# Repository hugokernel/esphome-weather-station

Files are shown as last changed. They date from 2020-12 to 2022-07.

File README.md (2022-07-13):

# ESPHome Weather Station

Read this in other language: [French](README.fr.md)

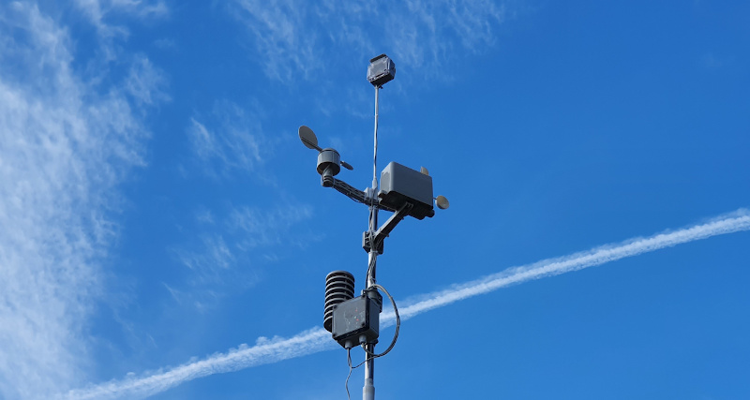
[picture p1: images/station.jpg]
Main photo of the weather station


## Introduction

The electronic part of this weather station is based on the model described in an article in Elektor magazine published in May 2020 entitled [Remake Elektor weather station](https://www.elektormagazine.com/labs/remake-elektor-weather-station) (an evolution of ESP32 Weather Station described in an article in the same magazine in January 2019).

The article details the creation of a weather station based on a set of sensors referenced WH-SP-WS02 ([Datasheet](docs/Weather_Sensor_Assembly_Updated.pdf)) whose original electronics are removed to be replaced by a sensor daughter board relaying the information to a motherboard built around an ESP32 (ESP32 Pico Kit).

An OpenSource firmware [GitHub - ElektorLabs/191148-RemakeWeatherStation: RemakeWeatherStation](https://github.com/ElektorLabs/191148-RemakeWeatherStation) is available to run the whole system. Unfortunately, I did not find my happiness with it, it is not yet complete enough and suffers from some shortcomings that make it very difficult to use it as is.

I therefore decided to use ESPHome as a replacement for the original program in order to simplify the development of functionality but above all to greatly extend its capabilities.

The board detailed in Elektor's article is finally limited to a voltage converter and a 5V/3V voltage adaptation for the ESP32.

It is therefore quite simple to recreate this weather station independently of Elektor's PCB. For the connections, please use the data included in the YAML file.

With the kind [permission of Elektor](https://www.elektormagazine.com/labs/remake-elektor-weather-station#comment-70057), the schematic diagrams are available here:  [Schematics](schematics/).

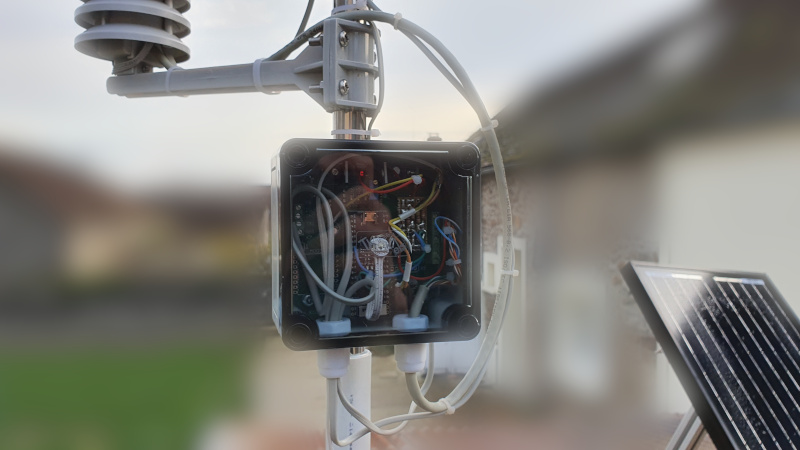
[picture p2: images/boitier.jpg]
Case photo


### Inspirations

* [Remake Elektor weather station | Elektor Magazine](https://www.elektormagazine.com/labs/remake-elektor-weather-station)
* [GitHub - mkuoppa/esphomeweatherstation: ESPHome based weatherstation station](https://github.com/mkuoppa/esphomeweatherstation)
* [ESP8266 Weather Station - with Wind and Rain Sensors | Tysonpower.de](https://tysonpower.de/blog/esp8266-weather-station)

## Features

* Measurement of temperature / relative humidity / atmospheric pressure
* Wind speed / Direction
* Precipitation daily / per minute
* Ambient brightness
* Input voltage
* Solar panel:
  * Voltage
  * Current
  * Power
  * Daily accumulated power
* RGB status led with WS2812
* All ESPHome features
  * MQTT
  * OTA (Over The Air updates)
  * [The list is long](https://esphome.io/)

Note: On the main picture of the weather station, there is a box on top, it is an [independent rain detection module](https://github.com/hugokernel/esphome-rain-detector).

## Installation

In order to install the firmware on the ESP32, I invite you to follow the procedure described on the ESPHome website: [Getting Started with ESPHome](https://esphome.io/guides/getting_started_command_line.html)

## Electronics

The Elektor electronic board is to be used as is or, in view of its simplicity, to be reproduced on a test board.

The Elektor publication is wrong, in fact, they use GPIO 34 (wind speed) and 38 (precipitation measurement) directly without a pullup resistor,
Moreover, these inputs / outputs do not integrate a pull-up resistor, **so it is necessary to add a pullup resistor (~10kOhms) on GPIO34 and GPIO38**.

## Mechanical

For the mast, I used a metal reinforced PVC tube that you can find in any DIY store in the plumbing department. In order to fix it on a wall, I modeled it on OpenSCAD [one piece](wall_pipe_support.scad) that I then printed in PETG.

Here is the printed piece next to the box containing the solar panel charger controller:

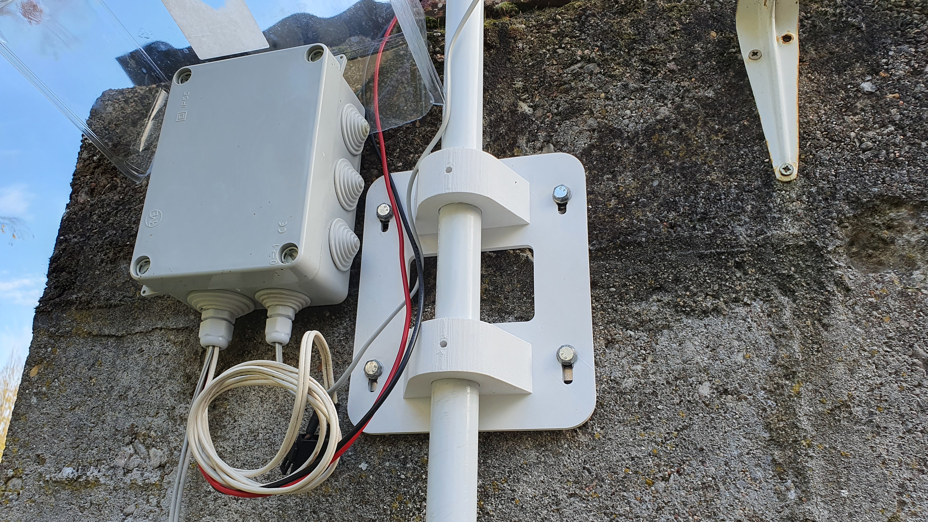
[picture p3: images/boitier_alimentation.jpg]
Photo of the power supply box


## Powering

One of the flaws that I reproach to the original Elektor board is to have linked the technology of the power source to the motherboard (in this case the lead battery), indeed, a [MAX8212](docs/MAX8211-MAX8212.pdf) used with some peripheral components allows to cut the power supply when it goes below a threshold defined by the value of 3 resistors. This threshold has been chosen to protect a lead battery.

Since a weather station is supposed to stay on all the time, I don't really understand the above choice because:

* We use a solar panel to charge the battery but in this case we are obliged to use a charge regulator which also protects the battery and therefore the integrated protection circuit is redundant and can even cause problems.
* The station is connected to an unlimited power source (domestic power via a regulator) and in this case the protection circuit is useless.

In the 2 cases mentioned above, a strong link is inserted on the motherboard with the battery technology, which should be done, imho, on an independent card / module.

For my part, I chose to power my weather station via a [30W solar panel](https://www.amazon.fr/gp/product/B07MZKLS4Z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) and a [relatively basic charge controller](https://www.amazon.fr/gp/product/B07K57WZVP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).

If you are using Elektor's motherboard with an independent load controller module, do not forget to lower the cut-off threshold of the MAX8212.

At the output of the solar panel, the [INA219](docs/ina219.pdf) circuit allows the power generated by the solar panel to be measured. I plan to replace it with [INA3221](docs/ina3221.pdf) in order to also measure the total consumption of the weather station and help me to refine the global consumption (a RFLink with [OpenMQTTGateway](https://github.com/1technophile/OpenMQTTGateway) and a second ESP32 kit is connected to the station).

I use a 7A lead battery recovered from an old inverter.

To size the whole thing, I recommend the [BatteryStuff Tools](https://www.batterystuff.com/kb/tools/solar-calculator.html) tool which is very handy.

Currently, I can't say that I have succeeded in making my weather station totally energy independent because of a bad exposure of my solar panel and a too high consumption of an additional module (rain detection module).

## Explanations

### Measurement of temperature / humidity / atmospheric pressure

These 3 quantities are measured by a Bosch BME280 sensor and its configuration in ESPHome is as follows:

```yaml
  - platform: bme280
    address: 0x76
    update_interval: 60s
    iir_filter: 16x
    temperature:
      name: "${friendly_name} temperature"
      oversampling: 16x
    humidity:
      name: "${friendly_name} humidity"
      oversampling: 16x
    pressure:
      name: "${friendly_name} pressure"
      oversampling: 16x
```

The sensor is to be put inside the box containing the original sensor electronics.

Initially, I also included an AM2320 sensor to compare the sensor values with the following configuration:

```yaml
  - platform: am2320
    setup_priority: -100
    temperature:
      id: am2320_temperature
      name: "${friendly_name} AM2320 temperature"
    humidity:
      id: am2320_humidity
      name: "${friendly_name} AM2320 humidity"
    update_interval: 60s
```

The temperatures and humidities of the sensors were averaged before being sent to Home Assistant (see below), it was of course possible to access the data of each sensor.

```yaml
  - platform: template
    name: "${friendly_name} temperature"
    icon: "mdi:thermometer"
    unit_of_measurement: "°C"
    lambda: |-
      return (
        id(bme280_temperature).state
        +
        id(am2320_temperature).state
      ) / 2;

  - platform: template
    name: "${friendly_name} humidity"
    icon: "mdi:water-percent"
    unit_of_measurement: "%"
    lambda: |-
      return (
        id(bme280_humidity).state
        +
        id(am2320_humidity).state
      ) / 2;
```

At the end of my tests, the BME280 sensor is more reliable and more accurate than the AM2320 sensor.

### Wind measurements

#### Speed

The wind speed sensor is connected to general input 34 and the ESPHome `pulse_meter` platform is now used to perform the measurement.

You need to add a pulling resistor on the GPIO34 (there is no internal pullup on this GPIO).

##### Speed calculation

1. First, check the number of pulses by revolution (`$number_of_pulses_by_revolution`)
2. Then, we need the circumference of the anemomenter, to do that, measure the radius of the anemomenter in meter.
\
In the example below, the radius is 9cm.
```
circumference_in_meter = $radius * 2 * π
circumference_in_meter = 0.09 * 2 * 3.14
circumference_in_meter = 0.565486678
```
3. Now, we can found the number of rotations per seconds by counting the number of pulses for one rotation
\
`rotations_per_sec = pulses / $number_of_pulses_by_revolution / 60`
4. Next, we multiply circumference and rotation par second to have the wind speed.
\
Note: 1.18 is a calibration factor to compensate the friction (you can adjust it).
```
meter_per_second = 1.18 * circumference_in_meter * $rotations_per_sec
meter_per_second = 1.18 * circumference_in_meter * 1 / $number_of_pulses_by_revolution / 60
meter_per_second = 1.18 * 0.565486678 / 2 / 60
meter_per_second = 0.005560619
```

Initial formula from https://github.com/mkuoppa/esphomeweatherstation/issues/2#issuecomment-812686624

For more information about calculation, see https://github.com/hugokernel/esphome-weather-station/issues/6

```yaml
  - platform: pulse_meter
    pin:
      number: GPIO34
      mode: INPUT
    id: wind_speed
    unit_of_measurement: 'm/s'
    name: "${friendly_name} wind speed"
    icon: 'mdi:weather-windy'
    internal_filter: 13us
    timeout: 5s
    filters:
      - multiply: 0.005560619
      - sliding_window_moving_average:
          window_size: 5
          send_every: 5
```

#### Direction

The wind direction is made in the sensor by means of magnets (switch reed) that switch resistors. Depending on the final value, the direction is deduced.

An example of the ESPHome configuration:

```yaml
  - platform: resistance
    sensor: source_sensor
    id: resistance_sensor
    configuration: DOWNSTREAM
    resistor: 10kOhm
    internal: true
    name: Resistance Sensor
    reference_voltage: 3.9V
    accuracy_decimals: 1
    filters:
      - median:
          window_size: 7
          send_every: 4
          send_first_at: 3
    on_value:
      - if:
          condition:
            sensor.in_range:
              id: resistance_sensor
              above: 15000
              below: 15500
          then:
            - text_sensor.template.publish:
                id: wind_dir_card
                state: "N"
            - sensor.template.publish:
                id: wind_heading
                state: 0.0
[...]
```

#### Rain

The measurement of precipitation is carried out by a system of pendulum composed of 2 cups, the water runs in the funnel of the sensor and fills the high cup, once the latter is filled, it tips by gravity. This movement is detected by a magnetic sensor (reed switch) and an impulse is generated.
The sensor documentation indicates that each pulse corresponds to 0.2794mm of precipitation.

```yaml
  - platform: pulse_counter
    pin:
      # Don't forget to add a pulling resistor, see README
      number: GPIO38
      mode: INPUT
    unit_of_measurement: 'mm'
    name: "${friendly_name} rain gauge"
    icon: 'mdi:weather-rainy'
    id: rain_gauge
    internal: true
    count_mode:
      rising_edge: DISABLE
      falling_edge: INCREMENT
    internal_filter: 13us
    update_interval: 60s
    filters:
      # Each 0.011" (0.2794mm) of rain causes one momentary contact closure
      - multiply: 0.2794
    accuracy_decimals: 4
```

In order to have more relevant information, these measurements are converted into precipitation per minute and the daily total is calculated.

```yaml
  - platform: integration
    name: "${friendly_name} rainfall per min"
    id: rain_per_min
    time_unit: min
    unit_of_measurement: 'mm'
    icon: 'mdi:weather-rainy'
    sensor: rain_gauge

  - platform: total_daily_energy
    name: "${friendly_name} total daily rain"
    power_id: rain_gauge
    unit_of_measurement: 'mm'
    icon: 'mdi:weather-rainy'
    # x60 To convert to aggregated rain amount
    filters:
      - multiply: 60
```

#### Brightness

Remember to position the brightness sensor as high as possible on your weather station so that it is not shaded by the mast or any part of the weather station.

```yaml
  - platform: tsl2561
    id: lux_meter
    name: "${friendly_name} ambient Light"
    address: 0x39
    update_interval: 5s
    integration_time: 14ms
    gain: 1x
```

## Files

* [weatherstation.yaml](weatherstation.yaml): The ESPHome configuration file
* [network.yaml](network.yaml): Your network information
* [secrets.yaml](secrets.yaml): The secret information about your network.
* [wall_pipe_support.scad](wall_pipe_support.scad): The OpenSCAD file for mat support.

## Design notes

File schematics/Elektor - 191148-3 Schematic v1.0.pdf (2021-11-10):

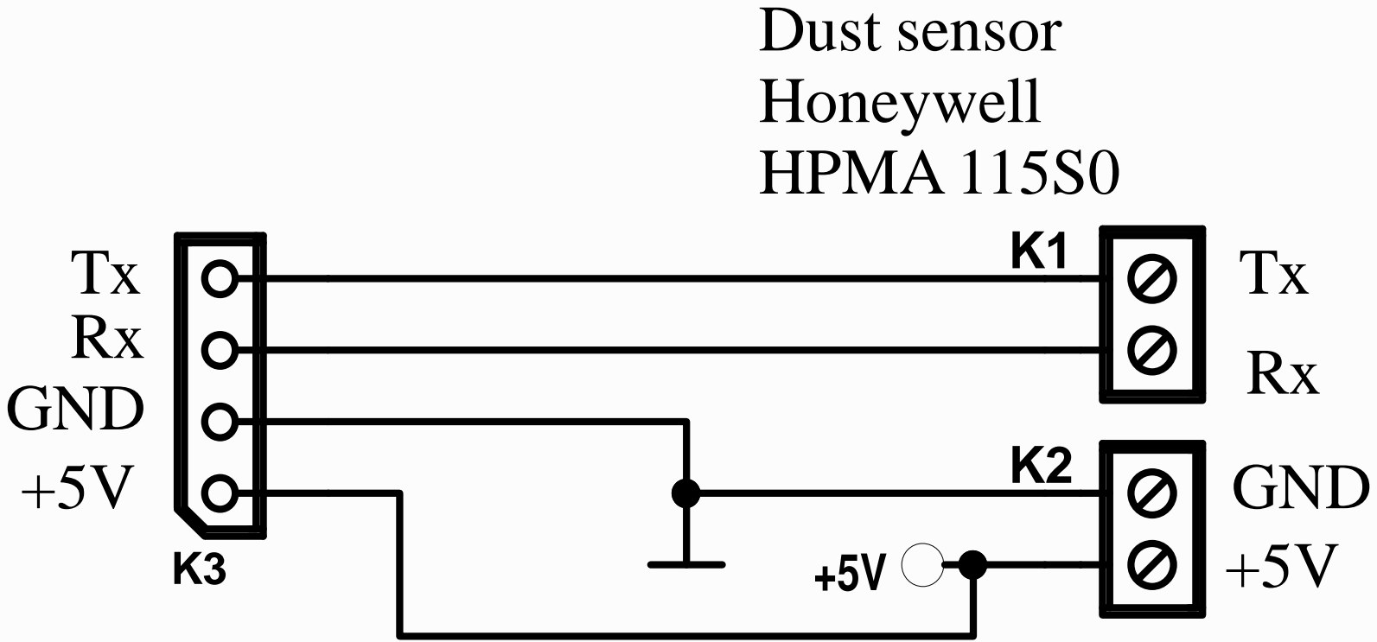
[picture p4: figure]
Dust sensor Honeywell HPMA 115S0 K1; GND

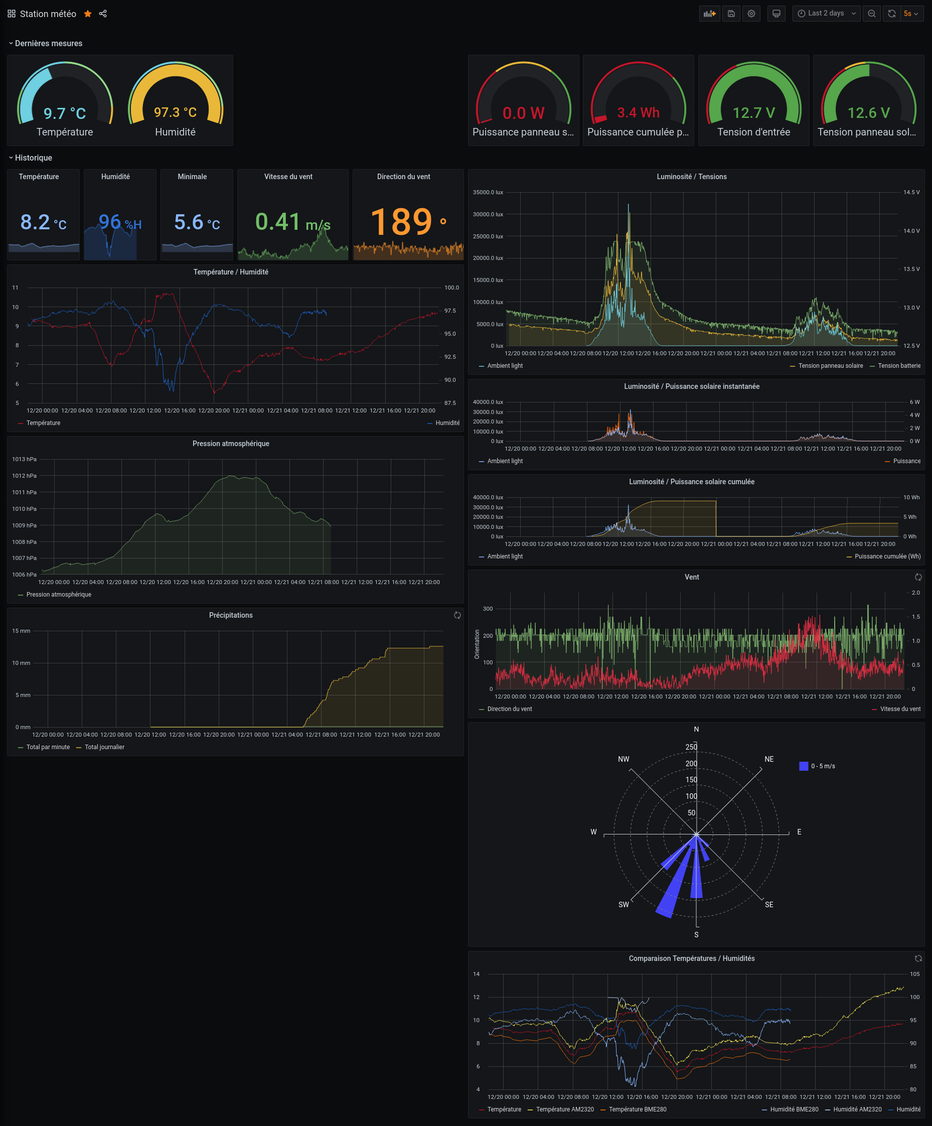
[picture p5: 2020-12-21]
images/grafana.png

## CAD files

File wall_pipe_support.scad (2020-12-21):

$fn = 60;

LENGTH = 180;
WIDTH = 150;
THICKNESS = 5;

OBLONG_DIAMETER = 5.5;
OBLONG_LENGTH = 15;

TUBE_DIAMETER = 26.9;

BOLT_DIAMETER = 4.5;
BOLT_HEAD_DIAMETER = 9;
NUT_DIAMETER = 8.25;
NUT_HEIGHT = 6;

module roundedBox(w,h,d,f){
	difference(){
        cube(size=[w, h, d], center=true);
		translate([-w/2,h/2,0]) cube(w/(f/2),true);
		translate([w/2,h/2,0]) cube(w/(f/2),true);
		translate([-w/2,-h/2,0]) cube(w/(f/2),true);
		translate([w/2,-h/2,0]) cube(w/(f/2),true);
	}
	translate([-w/2+w/f,h/2-w/f,-d/2]) cylinder(d,w/f, w/f);
	translate([w/2-w/f,h/2-w/f,-d/2]) cylinder(d,w/f, w/f);
	translate([-w/2+w/f,-h/2+w/f,-d/2]) cylinder(d,w/f, w/f);
	translate([w/2-w/f,-h/2+w/f,-d/2]) cylinder(d,w/f, w/f);
}

module oblong(diameter, length, thickness) {
    translate([-length / 2, 0, 0]) {
        hull() {
            cylinder(d=diameter, h=thickness);
            translate([length, 0, 0]) {
                cylinder(d=diameter, h=thickness);
            }
        }
    }
}

module nut(diameter, height) {
    cylinder(d=diameter, h=height, $fn=6);
    //%cylinder(d=7.8, h=height, $fn=40);
}

module tube_holder(diameter, length) {
    difference() {
        hull() {
            cube(size=[diameter * 3, length, 1], center=true);
            translate([0, length / 2, diameter]) {
                rotate([90, 0, 0]) {
                    cylinder(d=diameter * 2, h=length);
                }
            }
        }

        translate([0, length, diameter]) {
            rotate([90, 0, 0]) {
                cylinder(d=diameter, h=length * 2);
            }
        }

        translate([0, 0, diameter * 2 - 3]) {
            cylinder(d=BOLT_HEAD_DIAMETER, h=diameter);
        }
        cylinder(d=BOLT_DIAMETER, h=diameter * 2);
    }
}

module main() {
    item_position = LENGTH / 2 - 35;

    difference() {
        union() {
            difference() {
                roundedBox(LENGTH, WIDTH, THICKNESS, 10);

                for (position = [
                    [item_position, WIDTH / 2 - 15, 0],
                    [-item_position, WIDTH / 2 - 15, 0],
                    [item_position, -(WIDTH / 2 - 15), 0],
                    [-item_position, -(WIDTH / 2 - 15), 0],
                ]) {
                    translate(position) {
                        translate([0, 0, -THICKNESS]) {
                            oblong(OBLONG_DIAMETER, OBLONG_LENGTH, THICKNESS * 2);
                        }
                    }
                }

                roundedBox(LENGTH / 3.5, WIDTH / 1.8, THICKNESS * 2, 10);
            }

            for (x=[item_position, -item_position]) {
                translate([x, 0, 0]) {
                    rotate([0, 0, 90]) {
                        tube_holder(TUBE_DIAMETER, 30);
                    }
                }
            }
        }

        for (x=[item_position, -item_position]) {
            translate([x, 0, -THICKNESS / 2 - .1]) {
                nut(NUT_DIAMETER, NUT_HEIGHT);
            }
        }
    }
}

// Test
intersection() { translate([0, 0, 27]) cube(size=[43, 50, 35], center=true); tube_holder(TUBE_DIAMETER, 30); }
tube_holder(TUBE_DIAMETER, 30);
oblong(OBLONG_DIAMETER, OBLONG_LENGTH, THICKNESS);
difference() { cylinder(d=15, h=10); translate([0, 0, -.1]) nut(NUT_DIAMETER, NUT_HEIGHT); cylinder(d=BOLT_DIAMETER, h=100); }

!main();

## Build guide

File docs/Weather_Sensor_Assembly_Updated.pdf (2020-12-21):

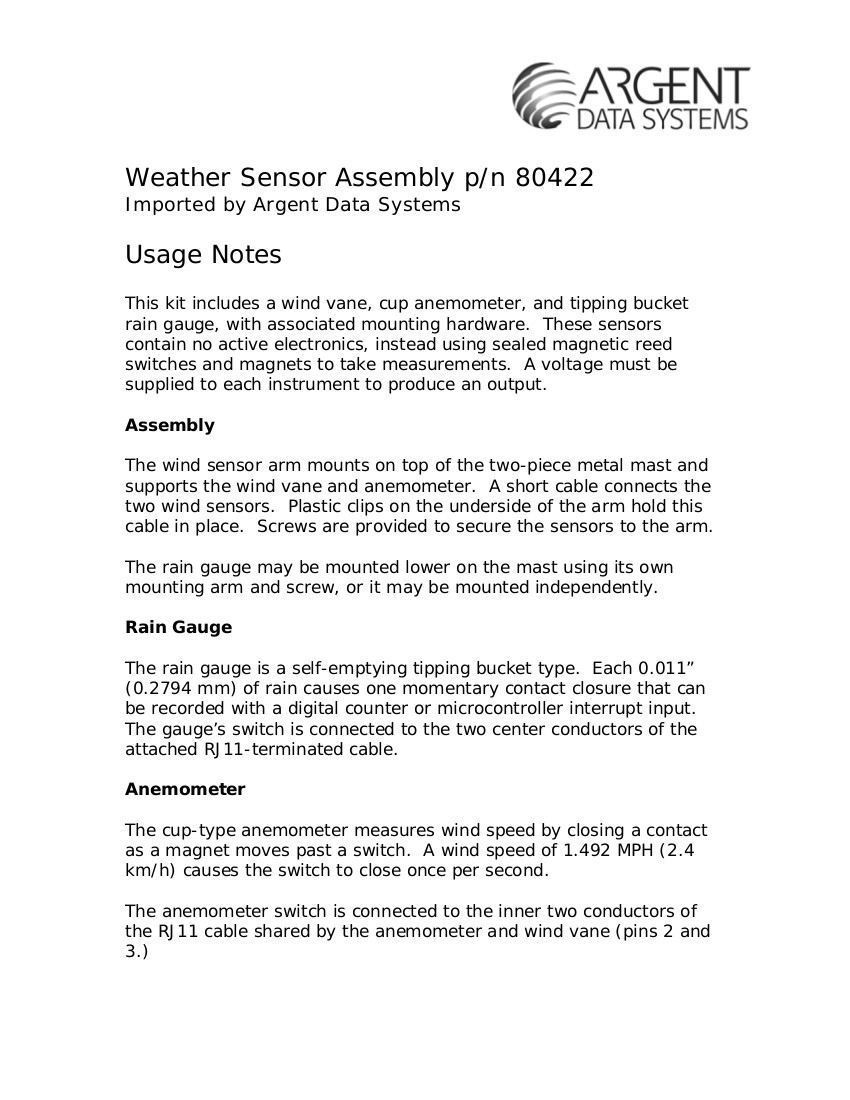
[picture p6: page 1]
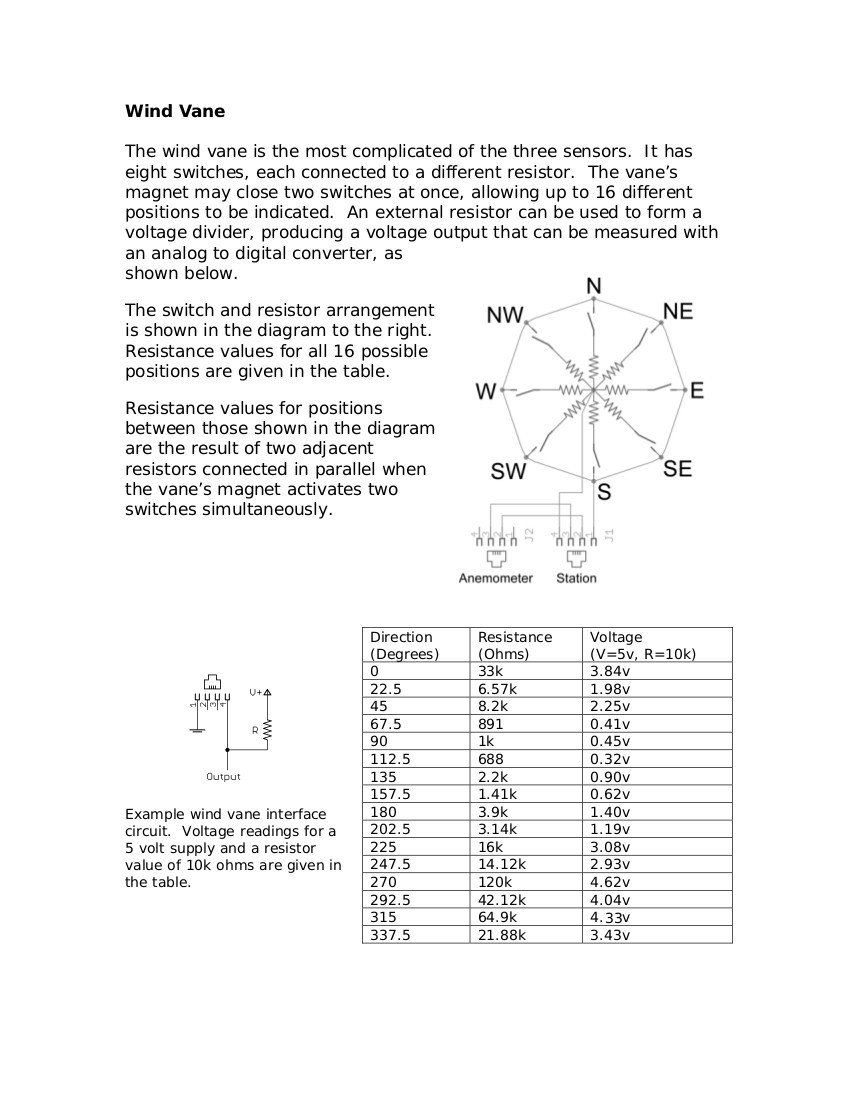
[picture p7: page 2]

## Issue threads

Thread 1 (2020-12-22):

[Feature Request] Particle sensor integration (HPMA115S0)

tom1422, 2020-12-22:
Hello,
Firstly I would like to say thank you for making this. It integrates much better with my Home Assistant installation and I haven't noticed any issues so far (expecting it to be far better than their original one in the long term). One question I have is the ability for a particle sensor to be linked. This would be really great. I am using the HPMA115S0 dust sensor and I would be happy to test any updates to see if they work and help fix bugs. Please let me know on your thoughts or if this would even work.
Kind regards,
Tom.

hugokernel, 2020-12-22:
Hi,

I think its integration would be very simple because this sensor sends its data via UART.

Unfortunately, I do not have this sensor so, I cannot test it, I invite you to consult the examples of the project https://github.com/felixgalindo/HPMA115S0 and the ESPHome UART page https://esphome.io/components/uart.html.

I will take your feedback to integrate this later.

Product page: https://sensing.honeywell.com/hpma115s0-xxx-particulate-matter-sensors
Datasheet: https://sensing.honeywell.com/honeywell-sensing-particulate-hpm-series-datasheet-32322550.pdf

Wumfie, 2020-12-23:
Hello,
I have created a first test build which uses a custom component in esphome. I will monitor it over a few days to test its reliability then post it here once i clean it up a little.

Wumfie, 2020-12-24:
I have uploaded the code to my github here:
[https://github.com/Wumfie/ESPHome-HPMA115S0-Sensor-Component](url)
Unfortunately, i couldn't get the yaml uart to work so instead I made a custom component. It has been working reliably for about 24 hours now but I welcome any improvements to the code.

aerodolphin, 2021-07-20:
Can you tell if it's working? \<\<\<I would like to buy the sensors.

tom1422, 2021-09-29:
Yeah its working fine. It might be worth getting one of the official ones listed here instead:
[https://esphome.io/index.html#air-quality](url)
So it will be compatible out of the box.

Closed 2021-10-06.

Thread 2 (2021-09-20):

Wiring Diagram

worldwidefelix, 2021-09-20:
Hi. Thank you for sharing awesome code with esphome.

While I am working with wring the wind sensor devices, I am confused with some wiring problem such as resistance, GPIO etc..

Would you upload your whole system's wiring diagram?

hugokernel, 2021-09-23:
Hi,

As I explain in the article, this project is derived from an article in Elektor magazine (https://www.elektormagazine.com/labs/remake-elektor-weather-station).

The schematics are available on the article page as a PDF:

* https://www.elektormagazine.com/files/attachment/31165
* https://www.elektormagazine.com/files/attachment/23317

worldwidefelix, 2021-09-24:
Thank you. So, did you follow every wiring step without modification just as diagrams in the files?

hugokernel, 2021-09-27:
> Thank you. So, did you follow every wiring step without modification just as diagrams in the files?

Yes because I used the original card from the article.

Closed 2021-11-10.

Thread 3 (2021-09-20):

sensor source

boelle, 2021-09-20:
@hugokernel hi, do you know where inside eu i can get the sensors? from china takes to long and i have to pay extra tax

boelle, 2021-09-20:
Q: could i just repeat like this? i plan to use adafruit sensor and if SDO pin is put to GND it changes from 0x76 og 0x77

  - platform: bme280
    address: 0x76
    update_interval: 60s
    iir_filter: 16x
    temperature:
      name: "${friendly_name} temperature"
      oversampling: 16x
    humidity:
      name: "${friendly_name} humidity"
      oversampling: 16x
    pressure:
      name: "${friendly_name} pressure"
      oversampling: 16x
  - platform: bme280
    address: 0x77
    update_interval: 60s
    iir_filter: 16x
    temperature:
      name: "${friendly_name} temperature"
      oversampling: 16x
    humidity:
      name: "${friendly_name} humidity"
      oversampling: 16x
    pressure:
      name: "${friendly_name} pressure"
      oversampling: 16x

boelle, 2021-09-20:
and i forgot to ask, (i cant figure the code yet), but does this part ever reset?

  - platform: pulse_counter
    pin:
      number: GPIO38
      mode: INPUT_PULLUP
    unit_of_measurement: 'mm'
    name: "Rain gauge"
    icon: 'mdi:weather-rainy'
    id: rain_gauge
    internal: true
    count_mode:
      rising_edge: DISABLE
      falling_edge: INCREMENT
    internal_filter: 13us
    update_interval: 60s
    filters:
      # Each 0.011" (0.2794mm) of rain causes one momentary contact closure
      - multiply: 0.2794
    accuracy_decimals: 4

i understand that rain per minute and daily rain are reset, but does the above work as a rain in total that is only reset if mcu is reset(power cycle)

hugokernel, 2021-09-23:
Did you find answers to all your questions?

boelle, 2021-09-23:
I think yes

My problem is more checking if my code is right

tor. 23. sep. 2021 12.33 skrev Charles R. ***@***.***>:

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

boelle, 2021-09-23:
But not home before evening

But if you have time to check my code for any obvious errors I would be
happy

tor. 23. sep. 2021 12.33 skrev Charles R. ***@***.***>:

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

hugokernel, 2021-09-23:
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

If you change the address, yes, it will work but after that, I don't really see the point of measuring the temperature in the sun ;)

hugokernel, 2021-09-23:
> i understand that rain per minute and daily rain are reset, but does the above work as a rain in total that is only reset if mcu is reset(power cycle)

The integration will start again at the beginning but is it really a problem? The assembly may reset often?

boelle, 2021-09-23:
Temperature in the sun makes sense when summer starts and you want to know
if you need a jacket or t-shirt or yo can go topless

tor. 23. sep. 2021 16.53 skrev Charles R. ***@***.***>:

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

boelle, 2021-09-23:
my code so far
```
esphome:
  name: vejrstation
  platform: ESP8266
  board: nodemcuv2
  esp8266_restore_from_flash: True

wifi:
  ssid: !secret wifi_ssid
  password: !secret wifi_password
  ap:
    ssid: vejrstation
    password: !secret ap_password

web_server:
  port: 80

logger:

api:

ota:

captive_portal:

i2c:
  frequency: 100kHz
  sda: D2
  scl: D1

sensor:
  - platform: pulse_counter
    pin:
      number: D6
      mode: INPUT_PULLUP
    unit_of_measurement: 'm/s'
    name: "Wind speed"
    icon: 'mdi:weather-windy'
    count_mode:
      rising_edge: DISABLE
      falling_edge: INCREMENT
    internal_filter: 13us
    update_interval: 60s
    # rotations_per_sec = pulses / 2 / 60
    # circ_m = 0.09 * 2 * 3.14 = 0.5652
    # mps = 1.18 * circ_m * rotations_per_sec
    # mps = 1.18 * 0.5652 / 2 / 60 = 0,0055578
    filters:
      - multiply: 0.0055578
      #- sliding_window_moving_average:
      #    window_size: 2
      #    send_every: 1

  - platform: pulse_counter
    pin:
      number: D5
      mode: INPUT_PULLUP
    unit_of_measurement: 'mm'
    name: "Rain gauge"
    icon: 'mdi:weather-rainy'
    id: rain_gauge
    internal: true
    count_mode:
      rising_edge: DISABLE
      falling_edge: INCREMENT
    internal_filter: 13us
    update_interval: 60s
    filters:
      # Each 0.011" (0.2794mm) of rain causes one momentary contact closure
      - multiply: 0.2794
    accuracy_decimals: 4

  - platform: integration
    name: "rainfall per min"
    id: rain_per_min
    time_unit: min
    unit_of_measurement: 'mm'
    icon: 'mdi:weather-rainy'
    sensor: rain_gauge

  - platform: total_daily_energy
    name: "total daily rain"
    power_id: rain_gauge
    unit_of_measurement: 'mm'
    icon: 'mdi:weather-rainy'
    # x60 To convert to aggregated rain amount
    filters:
      - multiply: 60

  - platform: bme280
    address: 0x76
    update_interval: 60s
    iir_filter: 16x
    temperature:
      name: "temperature"
      id: bme280_temperature
      oversampling: 16x
    humidity:
      name: "humidity"
      id: bme280_humidity
      oversampling: 16x
    pressure:
      name: "pressure"
      id: bme280_pressure
      oversampling: 16x

  - platform: bme280
    address: 0x77
    update_interval: 60s
    iir_filter: 16x
    temperature:
      name: "temperature(sun)"
      id: bme280_temperature_sun
      oversampling: 16x

  - platform: adc
    id: source_sensor
    pin: A0
    name: ADC
    #attenuation: 11db
    internal: true
    update_interval: 5s
    accuracy_decimals: 3
    filters:
    # - multiply: 3.3 ##built into Wemos
    # - multiply: 0.0009775171   #1/1023
    # - multiply: 0.846153 # 3.9 -> 3.3V

  - platform: resistance
    sensor: source_sensor
    id: resistance_sensor
    configuration: DOWNSTREAM
    resistor: 10kOhm
    internal: true
    name: Resistance Sensor
    #reference_voltage: 3.9V
    accuracy_decimals: 1
    filters:
      #- median:
      #    window_size: 7
      #    send_every: 4
      #    send_first_at: 3
      - heartbeat: 90s
    on_value:
      - if:
          condition:
            sensor.in_range:
              id: resistance_sensor
              above: 3132
              below: 3200
          then:
            - text_sensor.template.publish:
                id: wind_dir_card
                state: "N"
            - sensor.template.publish:
                id: wind_heading
                state: 0.0
      - if:
          condition:
            sensor.in_range:
              id: resistance_sensor
              above: 1600
              below: 1700
          then:
            - text_sensor.template.publish:
                id: wind_dir_card
                state: "NE"
            - sensor.template.publish:
                id: wind_heading
                state: 45.0
      - if:
          condition:
            sensor.in_range:
              id: resistance_sensor
              above: 250
              below: 350
          then:
            - text_sensor.template.publish:
                id: wind_dir_card
                state: "E"
            - sensor.template.publish:
                id: wind_heading
                state: 90.0
      - if:
          condition:
            sensor.in_range:
              id: resistance_sensor
              above: 550
              below: 650
          then:
            - text_sensor.template.publish:
                id: wind_dir_card
                state: "SE"
            - sensor.template.publish:
                id: wind_heading
                state: 135.0
      - if:
          condition:
            sensor.in_range:
              id: resistance_sensor
              above: 900
              below: 1100
          then:
            - text_sensor.template.publish:
                id: wind_dir_card
                state: "S"
            - sensor.template.publish:
                id: wind_heading
                state: 180.0
      - if:
          condition:
            sensor.in_range:
              id: resistance_sensor
              above: 2300
              below: 2450
          then:
            - text_sensor.template.publish:
                id: wind_dir_card
                state: "SW"
            - sensor.template.publish:
                id: wind_heading
                state: 225.0
      - if:
          condition:
            sensor.in_range:
              id: resistance_sensor
              above: 3900
              below: 4100
          then:
            - text_sensor.template.publish:
                id: wind_dir_card
                state: "W"
            - sensor.template.publish:
                id: wind_heading
                state: 270.0
      - if:
          condition:
            sensor.in_range:
              id: resistance_sensor
              above: 3500
              below: 3800
          then:
            - text_sensor.template.publish:
                id: wind_dir_card
                state: "NW"
            - sensor.template.publish:
                id: wind_heading
                state: 315.0

  - platform: template
    name: "Wind heading"
    id: wind_heading
    unit_of_measurement: "°"

text_sensor:
  - platform: template
    name: "Wind cardinal direction"
    id: wind_dir_card

interval:
  - interval: 60s
    then:
      - sensor.integration.reset: rain_per_min

# Enable time component to reset energy at midnight
time:
  - platform: sntp
    timezone: "Europe/Copenhagen"
```

boelle, 2021-09-23:
> > i understand that rain per minute and daily rain are reset, but does the above work as a rain in total that is only reset if mcu is reset(power cycle)
>
> The integration will start again at the beginning but is it really a problem? The assembly may reset often?

i plan to power it from 5v usb adapter so if power goes out it will reset

hugokernel, 2021-09-27:
> Temperature in the sun makes sense when summer starts and you want to know if you need a jacket or t-shirt or you can go topless tor. 23. sep. 2021 16.53 skrev Charles R. ***@***.***>:

I think there are much more reliable ways to measure the temperature felt by taking into account the wind, the humidity (dew point?).

boelle, 2021-09-27:
good thinking, that escaped my mind totally

will look in to it straight away since i have nothing better to do

Closed 2021-09-20.

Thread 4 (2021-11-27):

Wind speed GPIO38 doesn't have INPUT_PULLUP

sermayoral, 2021-11-27:
Hi friend. I have seen your project. It's amazing and thank you for sharing it. There is a thing that is wrong:

```
  - platform: pulse_counter
    pin:
      number: GPIO38
      mode: INPUT_PULLUP
```

According to the esp32 specifications:

_GPIOs 34 to 39 are GPIs – input only pins. These pins don’t have internal pull-up or pull-down resistors. They can’t be used as outputs, so use these pins only as inputs:_

More recent ESPHome versions tells you as well:

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

I hope it can help you :-)

I would like to ask you a doubt. I've got a WH-SP-WS01 anemometer. This one: https://a.aliexpress.com/_uAcawc

Do you think your calibration will be valid to me? Or i should calibrate it? Because it is a tedious process and I am not an expert on this subject.

Thank you very much!!

hugokernel, 2021-12-24:
Hi,

Sorry for the lag, I don't have much time right now, about GPIO, I have to take a look.

> Do you think your calibration will be valid to me? Or i should calibrate it? Because it is a tedious process and I am not an expert on this subject.

Yes, I think it's the same.

sermayoral, 2021-12-24:
Thank you very much ☺️

tom1422, 2022-02-18:
I have this issue as well. Not sure if it makes any difference though. I decided to change the Rain Meter and Wind Speed pins to GPIO 33 and GPIO 32 (on ADC1 because ADC2 apparently interferes with wifi).
This allows me to use input pull-up again as apparently pin 34 to 39 cannot be set as output, which is counter intuitive considering they are labelled as "GPIO".
Unfortunately, it means you have to ditch the Lora module (which i don't think they finished integrating) but it also makes it easier to connect it as the socket is already soldered. (D1 and D2 for the RFM95)
Just tried it and it made no difference (to using just using IO35 and no pullup). I will check with scope to double check.
Just checked with a scope and its reading the exact same values. Not sure if there's much point in changing the pins then.
Although I have been receiving very low wind-speed values since putting it up. I might buy a professional meter an put it beside the weather station to calibrate it to get better constants.

Closed 2022-04-25.

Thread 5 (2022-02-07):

Rain day is less then rain minute

Martinvdm, 2022-02-07:
Somehow the rain day sensor is lower then the rain minute sensor.
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
Any idea ?

hugokernel, 2022-06-21:
Hi,

Sorry for the late reply.

The `rainfall per min` is an integration sensor (https://esphome.io/components/sensor/integration.html) where the `total daily rain` is an total_daily_energy (https://esphome.io/components/sensor/total_daily_energy.html).
If it rains a lot in a short period of time, the value from the integration can increase very quickly.

The important thing is to make sure the accumulation is consistent at the end of the day.

++

Closed 2022-07-07.

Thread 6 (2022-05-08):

Is the multiplier with the anemometer correct

khenderick, 2022-05-08:
According to the datasheet one pulse per second corresponds with 2.4 km/h, which is 0.6666 m/s. For a update interval of 60s, I would think the multiplier would have to be 0.01111. The multiplier in weatherstation.yaml is set to 0.00555, which is about half that value, and I'm not sure I fully understand this difference.

hugokernel, 2022-06-21:
Hi,

Sorry for the late reply.

I agree with you, there has been a lot of wind here and the measurements are not consistent with the official stations.
The measurements are underestimated.
I have just redone some calculations and also found 0.01111.
The initial formula comes from a piece of generic code 'Davis 1640 Wind Gauge calculations' and seems inappropriate in this case.

My method for the calculation:

For 60 seconds, at 2.4Km/h, we have 60 pulses/minutes.

```
Coeff = 60 / 2.4 = 25
Speed(km/h) = PulseCount / Coeff
Speed(m/s) = PulseCount / (Coeff * 3.6)

Multiplier = 1 / (Coeff * 3.6)
Multiplier ~= 0.011111
```

And according to the measurements made this weekend, it is more in connection.

Have you made the change and do you confirm this result in practice?

khenderick, 2022-06-21:
Yeah, I used 0.01111 in my setup. I have no other device as reference, but it feels more in check with reality/predictions.

hugokernel, 2022-06-21:
Now, after reading this thread, I'm not sure about 0.11111 and my calculation https://community.home-assistant.io/t/measuring-wind-speed/395693/3

I need to investigate more.

nliaudat, 2022-06-21:
Perhaps it could help :
```
[Wind speed in m/s] = 2PI * [anemometer mid cup to axle lenght in m]  * [revolution per seconds]  * [unknown correction factor]
anemometer mid cup to axle lenght = 72.5 mm => 72.5/1000 = 0.0725 m for R
rotary encoder pulse per revolution : 36
revolution per seconds = pulses /36 /60
S = 2PI * 0.0725 * pulses /36 /60 = 0.00021089395
Speed m/s => Km/h : *3.6 => 0.00075921822
[unknown correction factor or friction] : mine is ~5 => 0.00075921822 *5 = 0.0037960911

You must paste that value in "pulse_meter" section of esphome.yaml
    filters:
      - multiply: 0.0037960911
```

From [https://github.com/nliaudat/weatherstation](https://github.com/nliaudat/weatherstation)

khenderick, 2022-06-21:
My diameter is ~18cm (hard to measure). This means a circumference of ~0.5m. Thus in theory, if the wind moves 0.5m/s, the anemometer rotates once per second. Ignoring any losses, this would mean 1.8km/h. The datasheet talks about 2.4km/h for one rotation per second, which is 0.69m/s. The "correction factor" would then be ~1.4.

It's not easy to verify without a known-correct device. Currently, my devices is more or less in the ballpark with what these "live wind map" sides say (3.82m/s measured vs 4m/s on the map).

hugokernel, 2022-07-04:
I made measurements with a calibrated anemometer and I confirm that the speed measured with the coefficient 0.0055 is not good and is 2 times lower, the good value is close to 0.0111.

However, I tried to calculate the multiplier with the formulas given in the links and I can't find 0.0111, whatever I do, I always find 0.0055, I will keep the reasoning applied in [this comment](https://github.com/hugokernel/esphome-weather-station/issues/6#issuecomment-1161515310) as a formula, it is the only one in phase with the measurements.

If someone can explain to me what the problem is with the other formulas, I'd love to hear it.

mkuoppa, 2022-07-04:
The windspeed calculation is just a rouge estimate that calculates the rotations speed of the anemometer in m/s. Then applies a small factor to compensate for drag etc (calibration factor). To get a more accurate measurement I recommend calibrating against another anemometer or other wind speed measurement. But hey my goal was not to create a precise measurement but rather something that can be used in home automation (ex. Retract my awning when the wind speed is over some threshold).

nliaudat, 2022-07-04:
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

It's seems that your friction factor is approx 2.
https://mdpi-res.com/d_attachment/sensors/sensors-14-21418/article_deploy/sensors-14-21418.pdf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

hugokernel, 2022-07-04:
@mkuoppa @nliaudat Did you see a problem with my approach from this comment https://github.com/hugokernel/esphome-weather-station/issues/6#issuecomment-1161515310 ?

hugokernel, 2022-07-04:
No need for the friction factor because the calculation is based on the manufacturer's calibration which indicates that at 2.4km/h, the switch closes 1 time per second.

Ref https://github.com/hugokernel/esphome-weather-station/blob/master/docs/Weather_Sensor_Assembly_Updated.pdf

hugokernel, 2022-07-07:
I made more precise measurements and after changing the measurement platform to `pulse_meter` (which allows faster and more accurate measurements), I came to the conclusion that the initial multiplier (0.0055) is the right one and therefore that 0.01111 is wrong for the sensor described in this project.
\
Moreover, I found the origin of the problem in my calculation, the documentation says: "A wind speed of 1.492 MPH (2.4 km/h) causes the switch to close on per second." and therefore, since we have 2 pulses per revolution and not one, my calculation was wrong and must be the one below:

For 60 seconds, at 2.4Km/h, we have **120** (not 60) pulses/minutes.

```
Coeff = 120 / 2.4 = 50
Speed(km/h) = PulseCount / Coeff
Speed(m/s) = PulseCount / (Coeff * 3.6)

Multiply = 1 / (Coeff * 3.6)
Multiply ~= 0.00555555
```

We end up with the same value calculated with the other method.

2 different calculation methods and a measurement made with an anemometer confirms the value of 0.005555 of the multiplier.

I don't know why you need a multiplier of 0.011111 but here are some tips to make sure everything is ok:
* Make sure you have enough pulses per rotation
* If your installation is a little isolated, in a wind corridor, this may explain why with an erroneous coefficient you find the same values as an official station
* The best thing to do is to find another anemometer and compare (there are very practical hand-held models for very little money)

I have some wind sensor related changes to commit to shortly but now I'll close this ticket.

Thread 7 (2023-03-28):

publish_state excepts float

dansity, 2023-03-28:
Hi,

When trying to flash it the Beaufort wind scale produces error as publish_state excepts float instead of char. It might be something that has changed with updates over time.

```
/config/esphome/weatherstation.yaml: In lambda function:
/config/esphome/weatherstation.yaml:77:40: error: cannot convert 'const char [2]' to 'float'
   77 |           id(wind_scale_code).publish_state("0");
      |                                        ^~~
      |                                        |
      |                                        const char [2]
In file included from src/esphome/core/controller.h:17,
                 from src/esphome/components/api/api_server.h:4,
                 from src/esphome/components/api/api_connection.h:6,
                 from src/esphome.h:3,
                 from src/main.cpp:3:
src/esphome/components/sensor/sensor.h:126:28: note:   initializing argument 1 of 'void esphome::sensor::Sensor::publish_state(float)'
  126 |   void publish_state(float state);
      |                      ~~~~~~^~~~~
```
github messed up the indentation, attached a screenshot for clarity
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

hugokernel, 2023-09-12:
Use ``` and not ` for multiline block.

About the problem, I will look at that when I have some time.

hugokernel, 2024-03-04:
Is this still relevant?
Have you updated ESPHome?

dansity, 2024-03-04:
Hi, for me it is not relevant in the sense that I removed the Beaufort scale and been using the rest of the script happily. So I'm not sure if it compiles with new ESPhome versions. If it does feel free to close the issue.

Closed 2024-05-30.

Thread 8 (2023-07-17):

Rain pr hour

Tntdruid, 2023-07-17:
Any way to add that?

```
  - platform: integration
    name: "rainfall per hour"
    id: rain_per_h
    time_unit: h
    unit_of_measurement: 'mm'
    icon: 'mdi:weather-rainy'
    sensor: rain_gauge
```

Does not work.

hugokernel, 2023-07-19:
Hi,

The simplest way to do that is to use the copy integration and use the result from the `rain_per_min` sensor like that:

```yaml
binary_sensor:
  - platform: copy
    source_id: rain_per_min
    name: "${friendly_name} rainfall per hour"
    filters:
      - multiply: 60
```

Tntdruid, 2023-07-19:
Thanks for the help.

Closed 2023-07-19.

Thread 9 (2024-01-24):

Values for wind direction

Liniik, 2024-01-24:
I need to use different reference voltage for the wind direction sensor (3.3 V) and I'm struggling with understanding how did you get values for `sensor.in_range`? I looked at the table in manual for the weather station and e.g. north is 33k Ohms but you have 15k - 15.5k Ohms. According to manual for mine version, resistances are the same so I don't know what should I set. Or was it just trial and error?

hugokernel, 2024-01-30:
I don't really remember, but I think I did the measurements on my station.

I invite you to do the same on yours, so you can be sure you're getting the right values.

Closed 2024-03-04.

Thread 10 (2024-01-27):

Question: Wiring.

jumper-d-1981, 2024-01-27:
I know this is not where I need to post this but cannot find anyone else even remotely close to a similar project so please please forgive my ignorance, and posting here.

I am in search of wiring specifics.  That is, I am working on this with my son, and he snipped the ends off both the (direction and speed) rj11 and the (rain bucket) rj11.  AND of course I cannot find them.  We bought the sensor kit from Spark fun, but not the board that accompanies it.  Figuring we would implement it with ESP32 at a future date, but now that date is here, I cannot figure out which wires are which...and thought it would be nice to be sure before experimenting.

It looks like I can tie certain wires to resistors on the + and others to GND, then jump the tied wires to pins to read...but no schematic I have looked at shows what color.

Thanks.

geejayem99, 2024-01-28:
Usually the wind speed is just a reed switch that closes 1 or 2 times per revolution, so check continuity on sets of 2 wires while rotating the anemometer until you find that. The remaining 2 just switch in different value resistors depending on the direction, so checking resistance on the remaining 2 wires, you should see those values as you rotate the wind direction vane. Rain bucket is also a reed switch, so use the continuity check to figure out which wires connect when you tilt the rain sensor back and forth

hugokernel, 2024-01-30:
As @geejayem99 said, it's very easy to find the wiring if you have a simple multi-meter in continuity mode, connect to one of the wires and ground, move one of the sensors and you'll see the signal close if you're connected to the right one.

Tntdruid, 2024-05-28:
@geejayem99 Can you share what color does what?

geejayem99, 2024-05-30:
No, not easily.

geejayem99, 2024-05-30:
This page may help. It doesn't mention colours, but has a diagram for that particular sensors wiring.
https://learn.sparkfun.com/tutorials/weather-meter-hookup-guide

Closed 2024-03-04.

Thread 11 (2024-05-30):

Error on daily rain total

HexnetIt, 2024-05-30:
HI I am getting the following errror

Failed config

sensor.total_daily_energy: [source /config/esphome/weather-station.yaml:64]

  Component sensor.total_daily_energy requires component time.
  platform: total_daily_energy
  name: ${friendly_name} total daily rain
  power_id: rain_gauge
  unit_of_measurement: mm
  icon: mdi:weather-rainy
  filters:
    - multiply: 60

HexnetIt, 2024-05-30:
Sorry forgoy to punt in

time:
  - platform: homeassistant
    id: homeassistant_time

All well now

Closed 2024-05-30.

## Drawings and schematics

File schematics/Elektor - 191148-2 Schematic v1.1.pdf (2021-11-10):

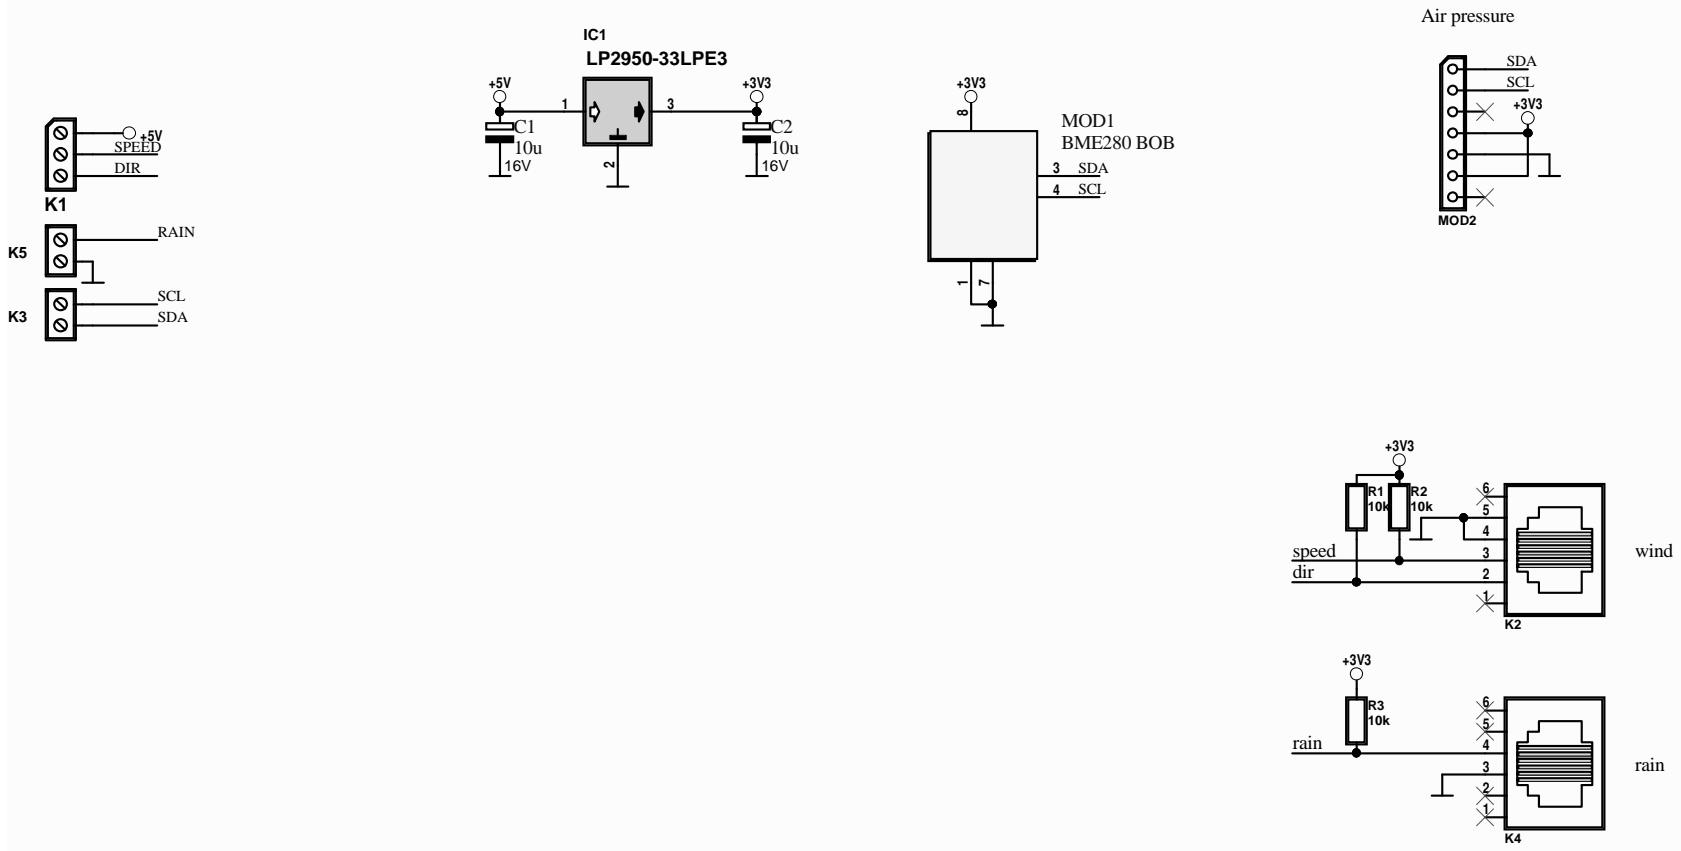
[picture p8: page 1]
SCL SDA; DIR; SPEED; RAIN; wind; rain; dir; speed; Air pressure; MOD2; SCL; SDA; GND; VCC; 8 MOD1 BME280 BOB; SDA SCL; IC1 LP2950-33LPE3

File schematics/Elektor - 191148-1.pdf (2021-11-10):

K1

R2

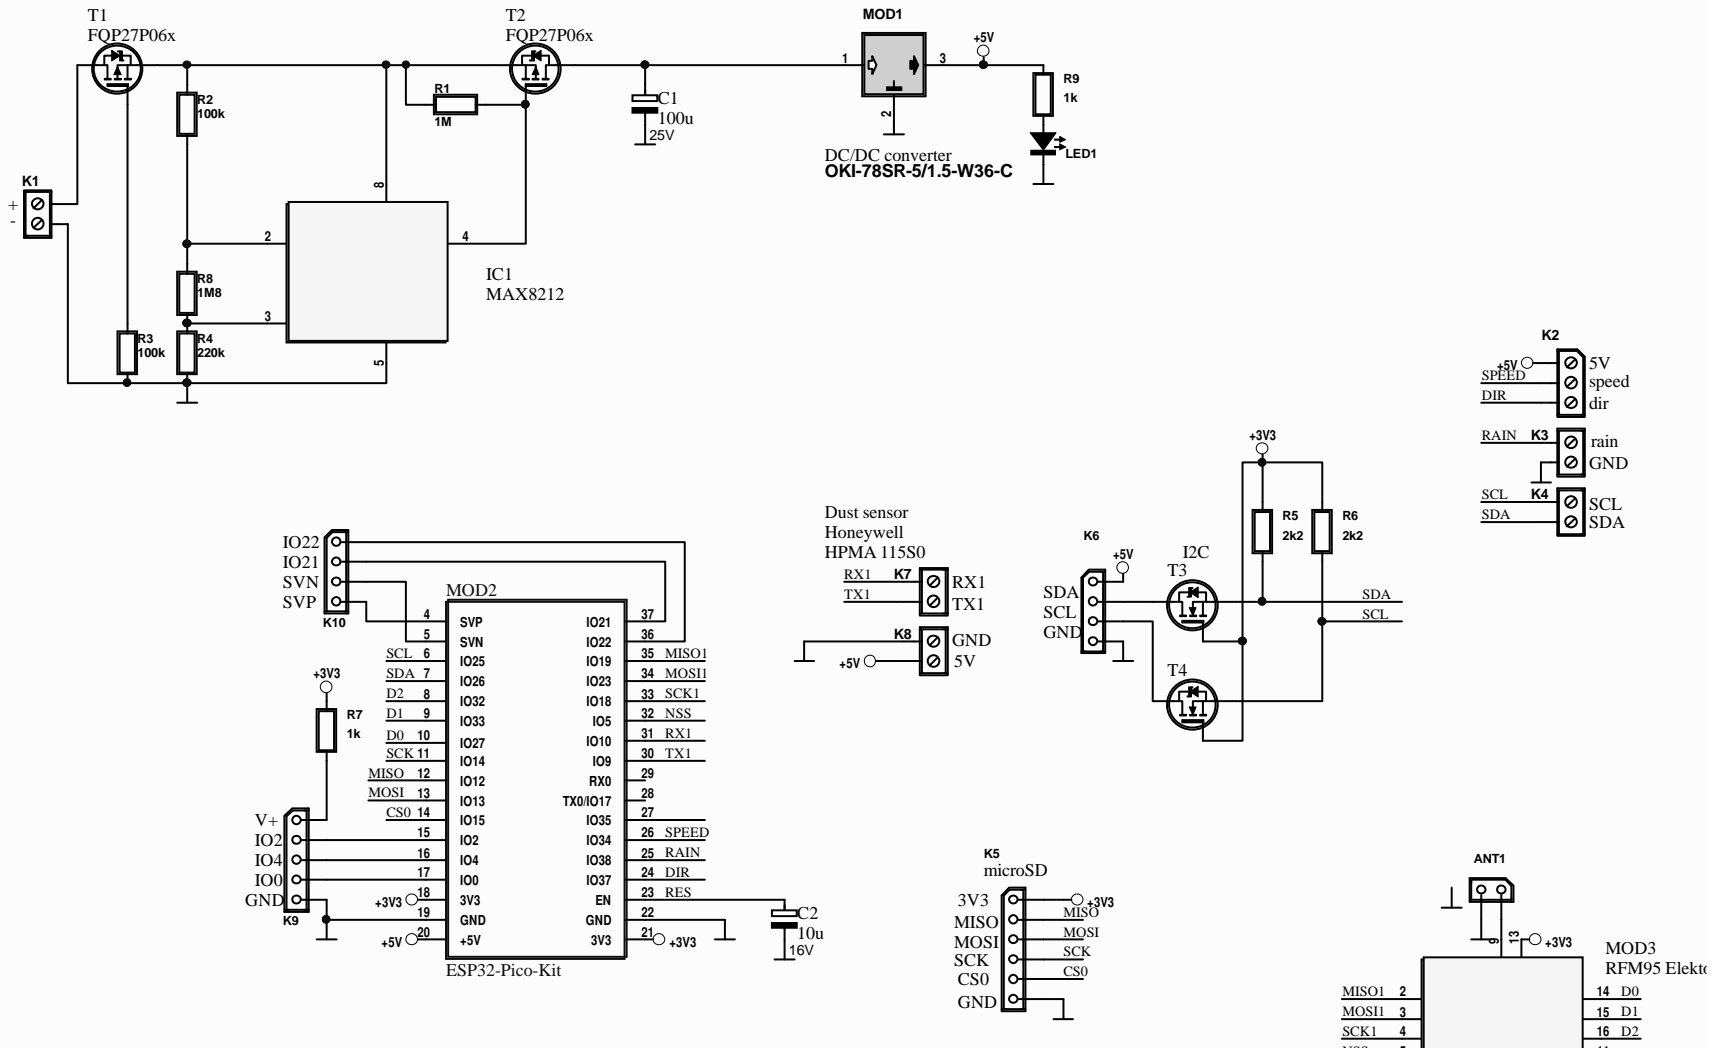
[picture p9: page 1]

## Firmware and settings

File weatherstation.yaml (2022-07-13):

.script_flashing: !include &flashing libraries/scripts/flashing.yaml

substitutions:
  name: weatherstation
  friendly_name: "Weather Station"

esphome:
  name: $name
  platform: ESP32
  board: pico32
  on_boot:
    priority: -10
    then:
      - script.execute: flashing

<<: !include network.yaml

captive_portal:

ota:
  password: !secret password

api:
  password: !secret password

sun:
  latitude: !secret latitude
  longitude: !secret longitude

logger:

i2c:
  frequency: 100kHz
  sda: GPIO26
  scl: GPIO25

script:
  - <<: *flashing

sensor:
  - platform: pulse_meter
    pin:
      # Don't forget to add a pulling resistor, see README
      number: GPIO34
      mode: INPUT
    id: wind_speed
    unit_of_measurement: 'm/s'
    name: "${friendly_name} wind speed"
    icon: 'mdi:weather-windy'
    internal_filter: 13us
    timeout: 5s
    filters:
      - multiply: 0.005560619
      - sliding_window_moving_average:
          window_size: 20
          send_every: 20

  - platform: copy
    name: '${friendly_name} wind speed average'
    icon: 'mdi:weather-windy'
    id: wind_speed_avg
    source_id: wind_speed
    unit_of_measurement: 'm/s'
    filters:
      - throttle_average: 5s

  - platform: copy
    name: '${friendly_name} wind speed (km/h)'
    id: wind_speed_kmh
    source_id: wind_speed
    unit_of_measurement: 'km/h'
    icon: 'mdi:weather-windy'
    filters:
      - multiply: 3.6

  - platform: copy
    name: '${friendly_name} wind speed average (km/h)'
    icon: 'mdi:weather-windy'
    id: wind_speed_kmh_avg
    source_id: wind_speed_avg
    unit_of_measurement: 'km/h'
    filters:
      - multiply: 3.6
    on_value:
      lambda: |-
        if (x < 1) {
          id(wind_scale_code).publish_state("0");
          id(wind_scale).publish_state("Calm");
        } else if (x >= 1 && x < 6) {
          id(wind_scale_code).publish_state("1");
          id(wind_scale).publish_state("Light Air");
        } else if (x >= 6 && x < 12) {
          id(wind_scale_code).publish_state("2");
          id(wind_scale).publish_state("Light Breeze");
        } else if (x >= 12 && x < 20) {
          id(wind_scale_code).publish_state("3");
          id(wind_scale).publish_state("Gentle Breeze");
        } else if (x >= 20 && x < 29) {
          id(wind_scale_code).publish_state("4");
          id(wind_scale).publish_state("Moderate Breeze");
        } else if (x >= 29 && x < 39) {
          id(wind_scale_code).publish_state("5");
          id(wind_scale).publish_state("Fresh Breeze");
        } else if (x >= 39 && x < 50) {
          id(wind_scale_code).publish_state("6");
          id(wind_scale).publish_state("Strong Breeze");
        } else if (x >= 50 && x < 62) {
          id(wind_scale_code).publish_state("7");
          id(wind_scale).publish_state("Near Gale");
        } else if (x >= 62 && x < 75) {
          id(wind_scale_code).publish_state("8");
          id(wind_scale).publish_state("Gale");
        } else if (x >= 75 && x < 89) {
          id(wind_scale_code).publish_state("9");
          id(wind_scale).publish_state("Severe Gale");
        } else if (x >= 89 && x < 103) {
          id(wind_scale_code).publish_state("10");
          id(wind_scale).publish_state("Storm");
        } else if (x >= 103 && x < 118) {
          id(wind_scale_code).publish_state("11");
          id(wind_scale).publish_state("Violent Storm");
        } else if (x >= 118) {
          id(wind_scale_code).publish_state("12");
          id(wind_scale).publish_state("Hurricane Force");
        } else {
          ESP_LOGD("main", "It shouldn't happen (wind_speed_kmh_avg: %f)", x);
        }

  - platform: pulse_counter
    pin:
      # Don't forget to add a pulling resistor, see README
      number: GPIO38
      mode: INPUT
    unit_of_measurement: 'mm'
    name: "${friendly_name} rain gauge"
    icon: 'mdi:weather-rainy'
    id: rain_gauge
    internal: true
    count_mode:
      rising_edge: DISABLE
      falling_edge: INCREMENT
    internal_filter: 13us
    update_interval: 60s
    filters:
      # Each 0.011" (0.2794mm) of rain causes one momentary contact closure
      - multiply: 0.2794
    accuracy_decimals: 4

  - platform: integration
    name: "${friendly_name} rainfall per min"
    id: rain_per_min
    time_unit: min
    unit_of_measurement: 'mm'
    icon: 'mdi:weather-rainy'
    sensor: rain_gauge

  - platform: total_daily_energy
    name: "${friendly_name} total daily rain"
    power_id: rain_gauge
    unit_of_measurement: 'mm'
    icon: 'mdi:weather-rainy'
    # x60 To convert to aggregated rain amount
    filters:
      - multiply: 60
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

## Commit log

2020-12-21 feat: remove am2320 sensor
2020-12-21 fix: cleanup, reactivate commented code
    [weatherstation.yaml]
2020-12-21 feat: add information about wall pipe support
    [wall_pipe_support.scad]
2021-11-10 feat: add schematic from elektor
    Closes #2
2022-04-25 fix: pullup resistor on gpio34 and 38
    Closes #4
    [weatherstation.yaml]
2022-07-13 feat: add wind speed template sensor in km/h
2022-07-13 feat: use pulse_meter integration instead pulse_counter for wind speed sensor
2022-07-13 feat: change sliding window moving range filter
